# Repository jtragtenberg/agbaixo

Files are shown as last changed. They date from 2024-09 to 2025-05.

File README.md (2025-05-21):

# Agbaixo
Instrumento Agbaixo (também chamado de Agbau ou Agbaça), em processo de criação pelo BongarBit

Watch the video (https://youtu.be/48ikO1KuL8A)
Vídeo de Ninho Brown, do Bongarbit, tocando o Agbau no Centro Cultural Grupo Bongar - Guitinho da Xambá em Olinda/PE

Na pasta Arduino está o Firmware em C++ do microcontrolador AVR responsável por receber os dados dos botões e sensores e mandar por protocolo MIDI USB para o Bela

Na pasta Bela está a engine de som em duas variantes para reproduzir os samples em tempo real juntamente com um processamento do sinal com uma envoltória exponencial otimizado para reduzir a demanda de processamento do Bela, opções de configuração do modo de disparo dos samples

# Para mandar o código para o Arduino:

Baixe e instale o Arduino na versão legado (1.8.x) em https://www.arduino.cc/en/software

Abra o programa Arduino (Arduino IDE)

Instale as bibliotecas colocando no diretório onde o Arduino for instalado, dentro da pasta libraries, todas as pastas que estão em Arduino/libraries deste repositório.

Na IDE do Arduino, vá nas configurações (File > Preferences) e adicione o texto na caixa de texto "Additional Board Manager URLs" o seguinte link: https://raw.githubusercontent.com/sparkfun/Arduino_Boards/main/IDE_Board_Manager/package_sparkfun_index.json

Vá em Tools>Board>Boards Manager e faça uma busca por Sparkfun AVR Boards e clique no botão "Install"

Vá em Tools>Board> e selecione a placa Arduino Pro Micro

Vá em Tools>Processor: e selecione o "ATmega 32u4 (5v, 16MHz)"

Identifique quais opções existem em Tools>Port>

Conecte o arduino no USB do computador

Note qual foi a opção nova que apareceu no submenu Tools>Port> e selecione ela

Abra o arquivo Arduino/agbaixo/agbaixo.ino e clique na barra de ferramentas da IDE do Arduino no botão "Upload" (o segundo da esquerda pra direita)

Se tudo der certo o código será enviado para a memória do Arduino.

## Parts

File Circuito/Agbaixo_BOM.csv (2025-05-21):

Reference | Value | Datasheet | Footprint | Qty | DNP
D1,D2,D3,D4,D5,D6,D7,D8,D9,D10,D11,D12,D13,D14,D15,D16 | D | ~ | Diode_THT:D_T-1_P5.08mm_Horizontal | 16
J1,J2 | Conn_01x12_Socket | ~ | Connector_PinSocket_2.54mm:PinSocket_1x12_P2.54mm_Vertical | 2
J3,J5,J6,J7,J8,J9,J10,J11,J12,J13,J14,J15,J16,J17,J18,J19,J20,J21,J22,J23 | Conn_01x02_Socket | ~ | Connector_JST:JST_EH_B2B-EH-A_1x02_P2.50mm_Vertical | 20
J4 | Conn_01x03_Socket | ~ | Connector_JST:JST_EH_B3B-EH-A_1x03_P2.50mm_Vertical | 1
J24,J25,J26,J27,J28,J29,J30,J31,J32,J33,J34,J35,J36,J37,J38,J39 | Conn_01x02_Pin | ~ | Connector_PinSocket_2.54mm:PinSocket_1x02_P2.54mm_Vertical | 16
R1,R2,R3,R4 | 220R | ~ | Resistor_THT:R_Axial_DIN0204_L3.6mm_D1.6mm_P5.08mm_Horizontal | 4

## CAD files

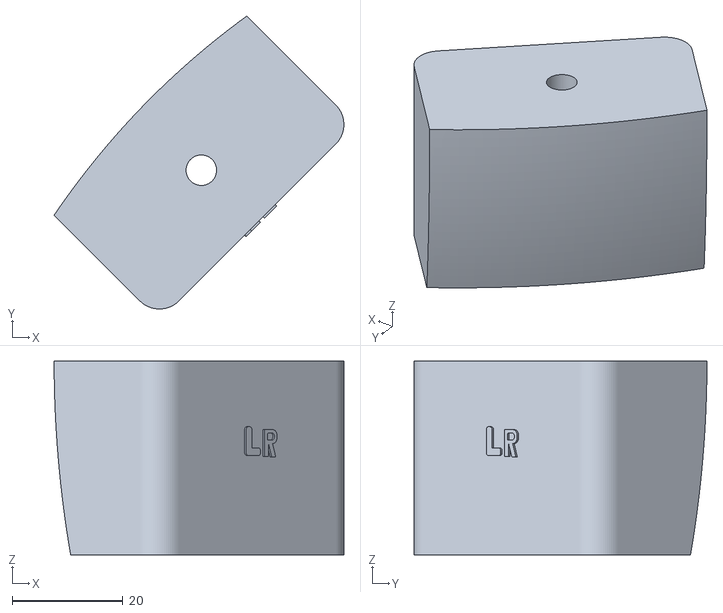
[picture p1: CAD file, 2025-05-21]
Structure/Cover_Holders/Piece1.stl
52.3 x 52.9 x 35.0

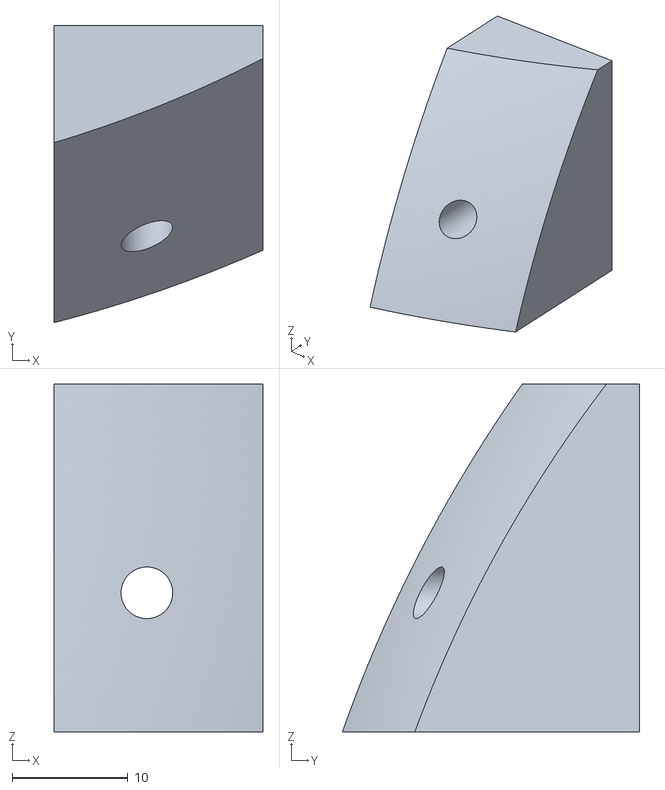
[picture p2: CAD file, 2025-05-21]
Structure/PCB_Base/pe2.stl
18.0 x 25.6 x 30.0

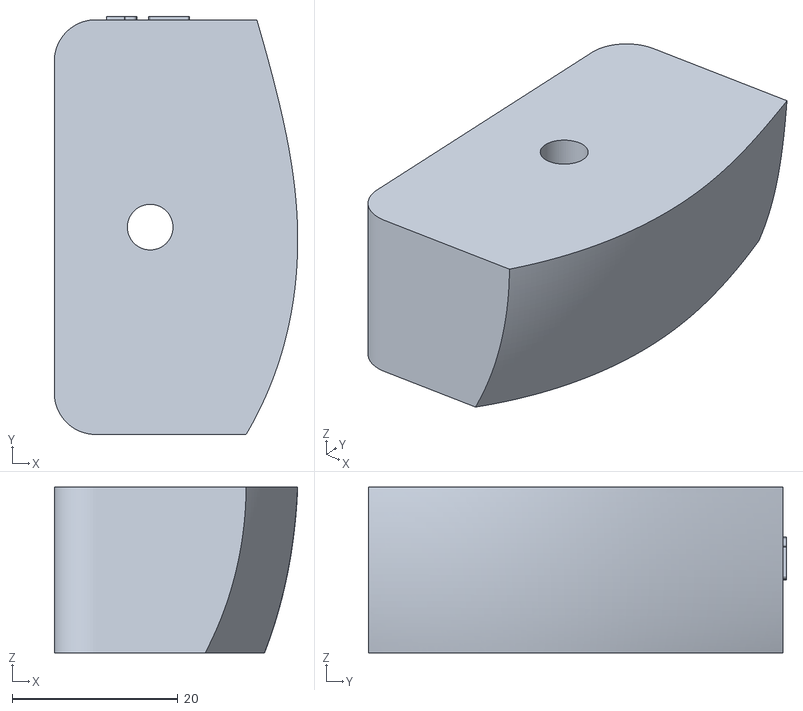
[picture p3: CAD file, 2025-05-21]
Structure/Cover_Holders/Piece6.stl
29.3 x 50.4 x 20.0

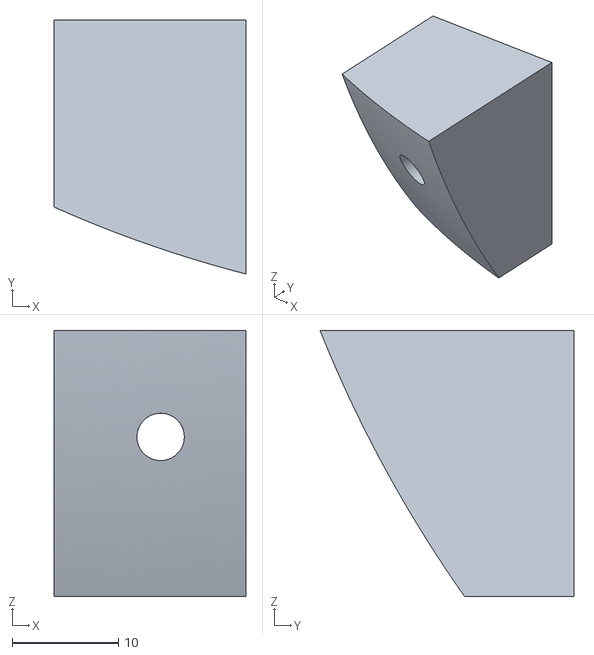
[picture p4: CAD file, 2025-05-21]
Structure/PCB_Base/pe4.stl
18.0 x 23.9 x 25.0

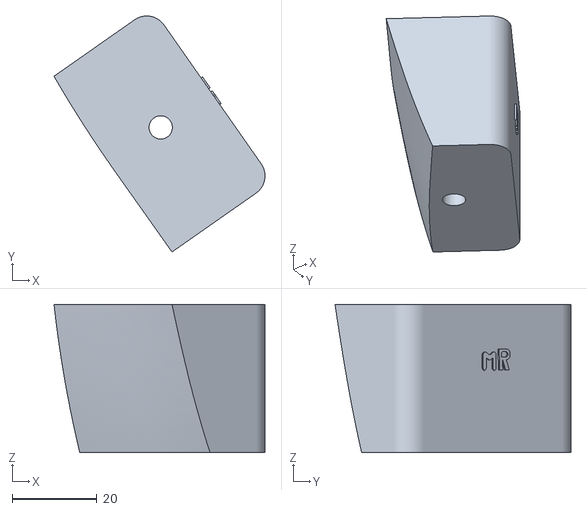
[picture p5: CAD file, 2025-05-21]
Structure/Cover_Holders/Piece3.stl
49.8 x 55.7 x 35.0

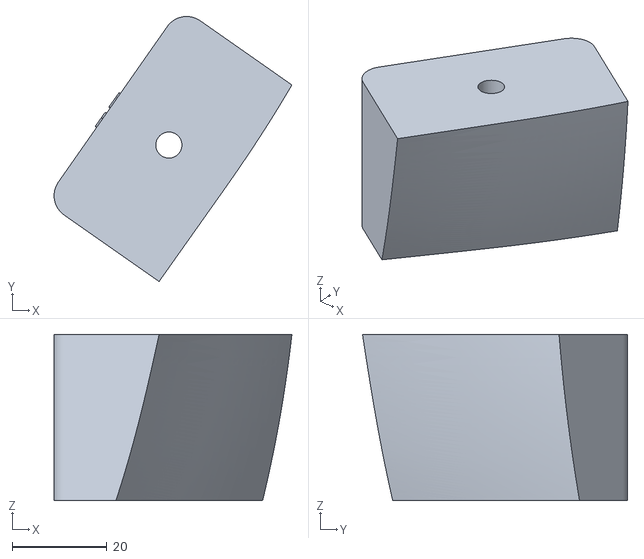
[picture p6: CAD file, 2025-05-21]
Structure/Cover_Holders/Piece4.stl
50.1 x 55.9 x 35.0

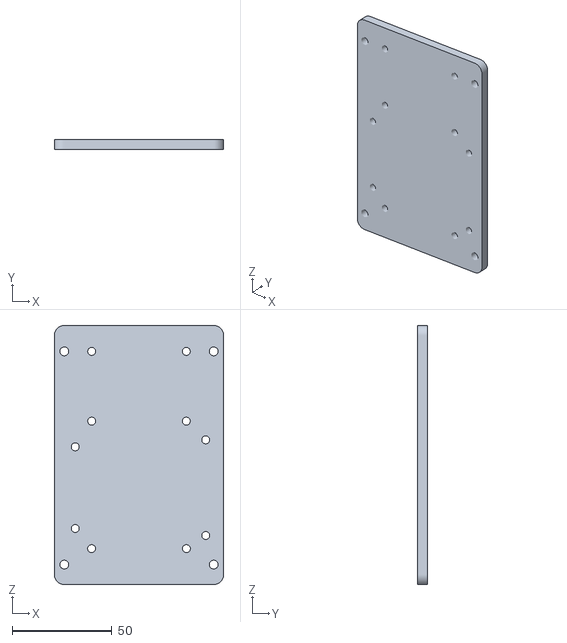
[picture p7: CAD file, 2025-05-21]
Structure/PCB_Base/base.stl
85.0 x 5.00 x 130.0

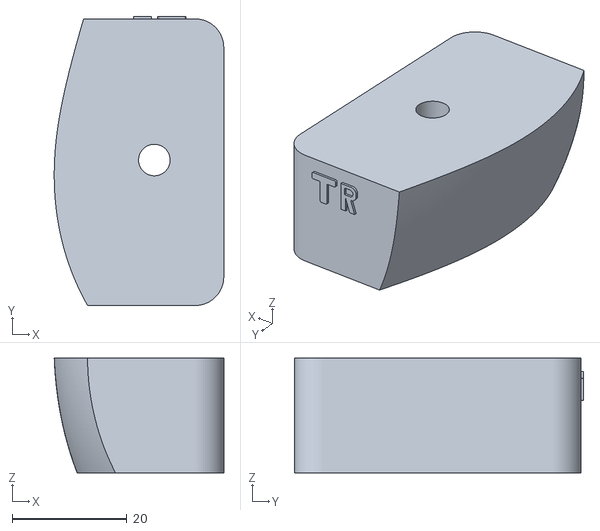
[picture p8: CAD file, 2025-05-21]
Structure/Cover_Holders/Piece5.stl
29.6 x 50.4 x 20.0

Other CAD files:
Structure/PCB_Base/pe1.stl
Structure/Cover_Holders/Piece2.stl
Structure/PCB_Base/pe3.stl
Structure/Cover_Holders/agbaixo_pieces.f3d
Structure/PCB_Base/Agbaixo_Base.f3d

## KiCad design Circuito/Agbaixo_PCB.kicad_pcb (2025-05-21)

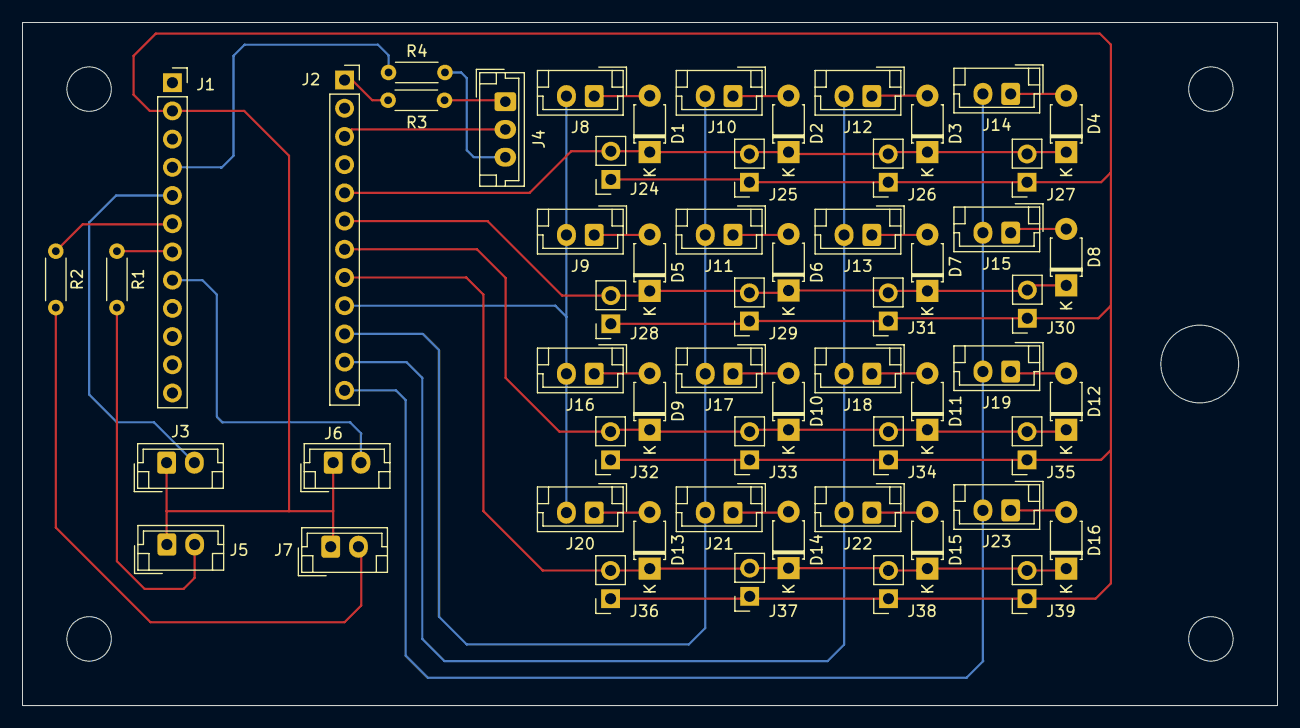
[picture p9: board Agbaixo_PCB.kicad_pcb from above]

Board: 2 copper layers, 113.0 x 61.5 mm, 59 parts (0 on the bottom side), 36 nets.

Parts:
D1, D2, D3, D4, D5, D6, D7, D8, D9, D10, D11, D12, D13, D14, D15, D16: D; D_T-1_P5.08mm_Horizontal
J1, J2: Conn_01x12_Socket; PinSocket_1x12_P2.54mm_Vertical
J3, J5, J6, J7, J8, J9, J10, J11, J12, J13, J14, J15, J16, J17, J18, J19, J20, J21, J22, J23: Conn_01x02_Socket; JST_EH_B2B-EH-A_1x02_P2.50mm_Vertical
J4: Conn_01x03_Socket; JST_EH_B3B-EH-A_1x03_P2.50mm_Vertical
J24, J25, J26, J27, J28, J29, J30, J31, J32, J33, J34, J35, J36, J37, J38, J39: Conn_01x02_Pin; PinSocket_1x02_P2.54mm_Vertical
R1, R2, R3, R4: 220R; R_Axial_DIN0204_L3.6mm_D1.6mm_P5.08mm_Horizontal

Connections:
unnamed: D1.2 (A), J8.1
unnamed: D1.1 (K), D2.1 (K), D3.1 (K), D4.1 (K), J2.5, J24.2, J25.2, J26.2, J27.2
unnamed: D2.2 (A), J10.1
unnamed: D3.2 (A), J12.1
unnamed: D4.2 (A), J14.1
unnamed: D5.2 (A), J9.1
unnamed: D5.1 (K), D6.1 (K), D7.1 (K), D8.1 (K), J2.6, J28.2, J29.2, J30.2, J31.2
unnamed: D6.2 (A), J11.1
unnamed: D7.2 (A), J13.1
unnamed: D8.2 (A), J15.1
unnamed: D9.2 (A), J16.1
unnamed: D10.2 (A), J17.1
unnamed: D9.1 (K), D10.1 (K), D11.1 (K), D12.1 (K), J2.7, J32.2, J33.2, J34.2, J35.2
unnamed: D11.2 (A), J18.1
unnamed: D12.2 (A), J19.1
unnamed: D13.2 (A), J20.1
unnamed: D13.1 (K), D14.1 (K), D15.1 (K), D16.1 (K), J2.8, J36.2, J37.2, J38.2, J39.2
unnamed: D14.2 (A), J21.1
unnamed: D15.2 (A), J22.1
unnamed: D16.2 (A), J23.1
unnamed: J1.2, J3.1, J5.1, J6.1, J7.1, J24.1, J25.1, J26.1, J27.1, J28.1, J29.1, J30.1, J31.1, J32.1, J33.1, J34.1, J35.1, J36.1, J37.1, J38.1, J39.1
unnamed: J1.4, R4.1
unnamed: J1.5, J3.2
unnamed: J1.6, R2.1
unnamed: J1.7, R1.1
unnamed: J1.8, J6.2
unnamed: J2.1, R3.1
unnamed: J2.3, J4.2
unnamed: J4.1, R3.2
unnamed: J4.3, R4.2
unnamed: J5.2, R1.2
unnamed: J7.2, R2.2
unnamed: J2.10, J10.2, J11.2, J17.2, J21.2
unnamed: J2.11, J12.2, J13.2, J18.2, J22.2
unnamed: J2.12, J14.2, J15.2, J19.2, J23.2
unnamed: J2.9, J8.2, J9.2, J16.2, J20.2

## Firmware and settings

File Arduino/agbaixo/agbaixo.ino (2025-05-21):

#include <Keypad.h>
#include <MIDIUSB.h>
#include <Bounce2.h>


//  GENERAL VARIABLES
const int MIDI_CHANNEL = 9;
const byte LINHAS = 4;
const byte COLUNAS = 4;
byte pinosColunas[LINHAS] = {2, 3, 4, 5};
byte pinosLinhas[COLUNAS] = {9, 8, 7, 6};
const byte pinoBotaoModo = 15;
const byte pinoLedBotaoModo = A1;
const byte pinoLooperLED = A2;
const byte pinoLooperPedal = A3;
char hexaKeys[LINHAS][COLUNAS] = {
  {'0', '4', '8', 'C'},
  {'1', '5', '9', 'D'},
  {'2', '6', 'A', 'E'},
  {'3', '7', 'B', 'F'}
};
Keypad teclado = Keypad(makeKeymap(hexaKeys), pinosLinhas, pinosColunas, LINHAS, COLUNAS); //initialize an instance of class NewKeypad
String msg;
int key_order[LINHAS * COLUNAS] = {
  1, 5, 9, 13,
  2, 6, 10,  14,
  3, 7, 11, 15,
  4, 8, 12, 16
};
const byte notaMidi[LINHAS * COLUNAS] = {
  60, 64, 68, 72,
  61, 65, 69, 73,
  62, 66, 70, 74,
  63, 67, 71, 75
};
const byte divisoesDoCompasso[8] = {
  2, 3, 4,
    6, 8,
  12, 16, 32
};
bool chavesApertadas [LINHAS * COLUNAS] = {
  false, false, false, false,
  false, false, false, false,
  false, false, false, false,
  false, false, false, false
};
int velocity = 100;

// TAP TEMPO VARIABLES
bool modoRepeat = false;
bool ttwaspressed = false;
int ultimoBotao[2];
int ultimoBaixo = 3;
int bpm = 120;
unsigned long previousMillis = 0;
unsigned long previousMillisMetro = 0;
int ledState = LOW;
Bounce botaoModo = Bounce();
int botoesApertados = 0;
unsigned long tempoBotao = 0;
unsigned long tempoBotaoAnterior = 0;

// LOOPER VARIABLES
Bounce looperPedal = Bounce();
bool isRecording = false;
bool isPlaying = false;
bool isOverdubbing = false;
bool ledStateLooper = false;
struct MidiMessage {
  byte type;
  //byte channel;
  byte data1;
  //byte data2;
  unsigned long timestamp;
};
const unsigned int loopbuffersize = 64;
const unsigned int maxOverdubLayers = 3;
MidiMessage midiLoop[maxOverdubLayers][loopbuffersize];
byte NloopMsgs[maxOverdubLayers];  // Number of messages in each layer
int currentLayer = 0;
unsigned long loopStartTime = 0;
unsigned long loopDuration = 0;
unsigned long currentLoopTime = 0;
int currentblinkt = 0;
int previousblinkt = 0;
int blinktime = 0;

// SETUP
void setup() {
  Serial.begin(9600);
  pinMode(pinoLedBotaoModo, OUTPUT);
  pinMode(pinoLooperLED, OUTPUT);
  botaoModo.attach(pinoBotaoModo, INPUT_PULLUP);
  botaoModo.interval(10);
  looperPedal.attach(pinoLooperPedal, INPUT_PULLUP);
  looperPedal.interval(10);
}

void loop(){
  //  BUTTON READING & DEBOUNCE
  if (teclado.getKeys()) {
    for (int i = 0; i < LIST_MAX; i++) {
      if (teclado.key[i].stateChanged) {
        switch (teclado.key[i].kstate) {  // Report active key state : IDLE, PRESSED, HOLD, or RELEASED
          case PRESSED:
              msg = " APERTADA.";
              if (key_order[teclado.key[i].kcode] > 8) { //se for botão
                dispararBotao(teclado.key[i].kcode);
              } else { //se for baixo
                dispararBaixo(teclado.key[i].kcode);
              }
              break;

          case HOLD:
            msg = " SEGURADA.";
            break;

          case RELEASED:
              msg = " SOLTA.";
              if (key_order[teclado.key[i].kcode] > 8) {
                soltarBotao(teclado.key[i].kcode);
              } else {
                soltarBaixo(teclado.key[i].kcode);
              }
              break;

          case IDLE:
            msg = " SOLTISSIMA.";
        }
        Serial.print("Tecla ");
        Serial.print(key_order[teclado.key[i].kcode]);
        Serial.println(msg);
      }
    }
  }

  //  TAP TEMPO
  botaoModo.update();
  if (botaoModo.fell()) {
    Serial.println("APERTOU MODO");
    tempoBotaoAnterior = tempoBotao;
    tempoBotao = millis();
    unsigned long intervalo = (tempoBotao - tempoBotaoAnterior);
    unsigned long bpmBotao = 1000. / intervalo * 60.;
    Serial.println(bpmBotao);
    bpm = bpmBotao;
    modoRepeat = true;
    Serial.println("MODO REPEAT");
    previousMillis = millis();
  }

  int botaoModoState = botaoModo.read();
  if (botaoModoState == LOW  && botaoModo.currentDuration() > 1000) {
    modoRepeat = false;
    Serial.println("MODO NOTA");
  }

  if (modoRepeat) {
    float interval = (1000 / bpm) * 60;
    unsigned long currentMillisMetro = millis();

    if (currentMillisMetro - previousMillisMetro > (interval / 2)) {
      previousMillisMetro = currentMillisMetro;

      // if the LED is off turn it on and vice-versa:
      if (ledState == LOW) {
        ledState = HIGH;
        digitalWrite(pinoLedBotaoModo, ledState);
      }
      else {
        ledState = LOW;
        digitalWrite(pinoLedBotaoModo, ledState);
        // set the LED with the ledState of the variable:
      }
    }

    unsigned long currentMillis = millis();

//TODO: não colocar o noteOff logo depois do noteON
//TODO: Corrigir algoritmo de contagem de botões apertados

    if (botoesApertados > 0) {
      if (currentMillis - previousMillis > (interval / divisoesDoCompasso[ultimoBaixo - 1] * 4.)) {
        previousMillis = currentMillis;
        noteOff(MIDI_CHANNEL - 1, ultimoBotao[1], 0);   // canal_midi, nota_midi, velocity_midi
        MidiUSB.flush();

        noteOn(MIDI_CHANNEL - 1, ultimoBotao[0], velocity);   // canal_midi, nota_midi, velocity_midi
        MidiUSB.flush();
        ttwaspressed = true;
      }
    }
    if (botoesApertados <= 0 && ttwaspressed){
        noteOff(MIDI_CHANNEL - 1, ultimoBotao[0], velocity);   // canal_midi, nota_midi, velocity_midi
        MidiUSB.flush();
        ttwaspressed = false;
    }
  } 
  else {
    digitalWrite(pinoLedBotaoModo, LOW);
  }

  //  LOOP
  loopstate();
  loopLED();
}

/////////////////////////////////////////////////////////////////////////////////////

//NOTE ON
void noteOn(byte channel, byte pitch, byte velocity) {
    midiEventPacket_t noteOn = {
    static_cast<uint8_t>(0x09),
    static_cast<uint8_t>(0x90 | channel),
    static_cast<uint8_t>(pitch),
    static_cast<uint8_t>(velocity)
};
  MidiUSB.sendMIDI(noteOn);
  if (isRecording) {
    recordMessage(0x09, pitch);
  }
}

//NOTE OFF
void noteOff(byte channel, byte pitch, byte velocity) {
  midiEventPacket_t noteOff = {
    static_cast<uint8_t>(0x08),
    static_cast<uint8_t>(0x80 | channel),
    static_cast<uint8_t>(pitch),
    static_cast<uint8_t>(velocity)
};
  MidiUSB.sendMIDI(noteOff);
  if (isRecording) {
    recordMessage(0x08, pitch);
  }
}

//CC
void controlChange(byte channel, byte control, byte value) {
    midiEventPacket_t event = {
    static_cast<uint8_t>(0x0B),
    static_cast<uint8_t>(0xB0 | channel),
    static_cast<uint8_t>(control),
    static_cast<uint8_t>(value)
};
  MidiUSB.sendMIDI(event);
}

void dispararBotao(int keyCode_) {
  if (modoRepeat) {
    //começa detecção de velocity com piezo
    botoesApertados++;
    Serial.println(botoesApertados);
    chavesApertadas[keyCode_] = true;
    ultimoBotao[1] = ultimoBotao[0];
    ultimoBotao[0] = notaMidi[keyCode_];
  } 
  else {
    noteOn(MIDI_CHANNEL - 1, notaMidi[keyCode_], velocity);   // Channel 0, middle C, normal velocity
    MidiUSB.flush();
  }
}

void soltarBotao(int keyCode_) {
  if (modoRepeat) {
    botoesApertados--;
    Serial.println(botoesApertados);
    chavesApertadas[keyCode_] = false;
  } else {
    noteOff(MIDI_CHANNEL - 1, notaMidi[keyCode_], 0);  // Channel 0, middle C, normal velocity
    MidiUSB.flush();
  }
}

void dispararBaixo(int keyCode_) {
  if (modoRepeat) {
    ultimoBaixo = key_order[keyCode_];
    chavesApertadas[keyCode_] = true;
  } else {
    //Dispara a nota
    noteOn(MIDI_CHANNEL - 1, notaMidi[keyCode_], velocity);   // Channel 0, middle C, normal velocity
    MidiUSB.flush();
  }
}

void soltarBaixo(int keyCode_) {
  if (modoRepeat) {
  chavesApertadas[keyCode_] = false;
  } else {
    noteOff(MIDI_CHANNEL - 1, notaMidi[keyCode_], 0);  // Channel 0, middle C, normal velocity
    MidiUSB.flush();
  }
}

int contagemDeBotoesApertados(){
  int c = 0;
  for (int i=9; i<=15; i++){
    if (chavesApertadas[i]) {
      c++;
    }
  }
  return c;
}



void loopstate(){
  looperPedal.update();
  if (looperPedal.fell()) {
    if (!isRecording && !isPlaying) {
      startRecording();
    } 
    else if (isRecording && !isPlaying) {
      stopRecording();
    } 
    else if (isPlaying && !isOverdubbing) {
      startOverdub();
    }
    else if (isPlaying && isOverdubbing){
      stopOverdub();
    }
  }
  if (isRecording && NloopMsgs[currentLayer]==loopbuffersize){
    stopRecording();
  }
  if (isOverdubbing && ((currentLoopTime%loopDuration)<=0.01 || NloopMsgs[currentLayer]==loopbuffersize)){
    stopOverdub();
  }
  if (isPlaying) {
    int looperpedalstate = looperPedal.read();
    if (looperpedalstate == LOW && looperPedal.currentDuration() > 1000) {
      isRecording = false;
      isPlaying = false;
      isOverdubbing = false;
      ledStateLooper = false;
      for (int i=0;i<loopbuffersize;i++){
        for (int layer=0; layer<maxOverdubLayers; layer++) {
          midiLoop[layer][i].type = 0;
          //midiLoop[layer][i].channel = 0;
          midiLoop[layer][i].data1 = 0;
          //midiLoop[layer][i].data2 = 0;
          midiLoop[layer][i].timestamp = 0;
        }
      }
      for (int layer=0; layer<maxOverdubLayers; layer++) {
        NloopMsgs[layer] = 0;
      }
      currentLoopTime = 0;
      loopStartTime = 0;
      currentLayer = 0;
      currentblinkt = 0;
      previousblinkt = 0;
      blinktime = 0;
      Serial.println("ERASED LOOP");
    }
    else{
      playLoop();
    }
  }
}



void startRecording() {
  Serial.println("Recording Started");
  isRecording = true;
  isPlaying = false;
  NloopMsgs[currentLayer] = 0;  // Reset the current layer's message count
  if (currentLayer==0){
    loopStartTime = millis();
  }
}

void stopRecording() {
  Serial.println("Recording Stopped");
  isRecording = false;
  isPlaying = true;

  NloopMsgs[currentLayer];  // Set loopLength to the current layer's message count

  if (currentLayer==0){
    loopDuration = millis() - loopStartTime;
  }
  previousblinkt = millis();
}



void startOverdub(){
  if (currentLayer < maxOverdubLayers) {
    Serial.println("Overdub Started");
    isOverdubbing = true;
    isRecording = true;
    currentLayer++;
    NloopMsgs[currentLayer] = 0;  // Start a new layer
  }
}

void stopOverdub(){
  Serial.println("Overdub Stopped");
  isOverdubbing = false;
  isRecording = false;
}



void recordMessage(byte type, byte data1) {
  if (NloopMsgs[currentLayer] < loopbuffersize) {
    midiLoop[currentLayer][NloopMsgs[currentLayer]].type = type;
   // midiLoop[currentLayer][NloopMsgs[currentLayer]].channel = channel;
    midiLoop[currentLayer][NloopMsgs[currentLayer]].data1 = data1;
   // midiLoop[currentLayer][NloopMsgs[currentLayer]].data2 = data2;
    midiLoop[currentLayer][NloopMsgs[currentLayer]].timestamp = millis() - loopStartTime;
    NloopMsgs[currentLayer]++;
  }
}

void playLoop() {
  currentLoopTime = millis() - loopStartTime;
  for (int layer = 0; layer <= currentLayer; layer++) {
    for (int i = 0; i < NloopMsgs[layer]; i++) {
      if (midiLoop[layer][i].timestamp <= currentLoopTime) {
        if (midiLoop[layer][i].type == 0x09) {
          noteOn(MIDI_CHANNEL, midiLoop[layer][i].data1, velocity);
          MidiUSB.flush();
        } else if (midiLoop[layer][i].type == 0x08) {
          noteOff(MIDI_CHANNEL, midiLoop[layer][i].data1, 0);
          MidiUSB.flush();
        }
        midiLoop[layer][i].timestamp += loopDuration;
      }
    }
  }
}



void loopLED(){
  if (!isRecording && !isPlaying) {
    digitalWrite(pinoLooperLED,LOW);
    ledStateLooper=false;
  } 
  else if (isRecording) {
    digitalWrite(pinoLooperLED,HIGH);
    ledStateLooper=true;
  } 
  else if (isPlaying) {
    blinkloop();
  }
}

void blinkloop(){
  int blinktime = loopDuration / 4;
  currentblinkt = millis();
  if (currentblinkt - previousblinkt >= blinktime) {
    previousblinkt = currentblinkt;
    if (!ledStateLooper) {
      digitalWrite(pinoLooperLED, HIGH);
      ledStateLooper = true;   
    } else {
      digitalWrite(pinoLooperLED, LOW);
      ledStateLooper = false;
    }
  }
}

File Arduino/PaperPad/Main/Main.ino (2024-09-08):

#include <MIDIUSB.h>
#include <MIDI.h>

// SETUP
const int PadPin = 21;

//MIDI settings
MIDI_CREATE_DEFAULT_INSTANCE();
int note = 38;
int channel = 1;

unsigned long ISRtime = 500;  // interruption time in microseconds (e.g., 500000 us = 0.5 seconds)
void setup() {
  // Set the pads and buttons
  pinMode(PadPin,INPUT);
  // Initialize USB Serial for debugging (optional)
  Serial.begin(31250);
  MIDI.begin(channel);
  // Disable global interrupts while setting up the timer
  cli();
  // Convert microseconds to seconds
  double ISRtime_sec = ISRtime / 1000000.0;
  // Calculate the timer compare match register value based on blink time
  // F_CPU      = 16 MHz (16,000,000 Hz)
  // Prescaler  = 1024
  // Formula: OCR1A = (F_CPU / Prescaler) * (Blink Time in seconds) - 1
  unsigned long compareMatchValue = (16e6 / 1024) * ISRtime_sec - 1;
  // Configure Timer1
  TCCR1A = 0;
  TCCR1B = 0;
  TCCR1B |= (1 << WGM12);              // CTC mode
  TCCR1B |= (1 << CS10) | (1 << CS12); // Prescaler 1024
  OCR1A = compareMatchValue;           // Set compare match register value
  // Enable Timer Compare Interrupt
  TIMSK1 |= (1 << OCIE1A);
  // Enable global interrupts
  sei();
}



// INTERRUPTION ROUTINE

int padRead = 0;
float pressure = 0;
int s = 0;
ISR(TIMER1_COMPA_vect) {
  padRead = analogRead(PadPin);  // reads the input pin [0 : 1023]
  pressure = filter(padRead,pressure,0.6,0.9);
  key(pressure, 15, 5);
  //s = switchMode(map(pressure,0,750,0,127), note);
}



// LOOP ROUTINE (IN CASE OF TESTING)
void loop() {
}

//////////////////////////////////////////////////////////////////////////////////////////////////////////////////////////////////////////

//SWITCH MODE
const int switcht = 20; //ms
const int switchon = 25; // pressure threshold to activate the switch
const int switchoff = 15; // pressure threshold to deactivate the switch
int switchbuffer[2];
int switchoutput = 0; //switch velocity [0 -> 127]

int switchMode(int input, int note) {
  unsigned long t0 = 0; //ms
  switchbuffer[1] = switchbuffer[0];
  switchbuffer[0] = input;
  if (switchbuffer[0] >= switchon){
    if (switchoutput == 0) {
      noteOn(channel, 38, 127);
      MidiUSB.flush();
      t0 = millis(); // Start debounce timer
    }
    if (switchbuffer[0] != switchbuffer[1]){
      controlChange(0, 11, map(switchbuffer[0],switchon,127,0,127)); //Control Change 11 -> Expression Controller (mapped to pressure aftertouch)
      MidiUSB.flush();
    }
    switchoutput = 127;
  } 
  else if (switchbuffer[0] <= switchoff && (millis() - t0) >= switcht) {     // Debounce period has passed
    if (switchoutput == 127) {
      controlChange(channel,11,0);
      noteOff(channel, 38, 0);
      MidiUSB.flush();

    }
    switchoutput = 0;
  }
  return switchoutput;
}



// KEY MODE
int index = 0;
int debounce = 0;
const int winsize = 5;
float detection_buffer[winsize];
bool noteon = false;

void key(float pressure, float derthresh, float pthresh) {
  // auxiliar parameters which can be fine tuned
  const int derscale = 3;
  const int debouncesmps = 150;
  float der = 0;

  // allow readings of pressure according to the derivative scale chosen
  index++;
  if(index==derscale){

    //calculate the derivative of the pressure each derscale samples
    der = filter(Derivative(pressure),der,0.1,0.3);

    Serial.print("ref1, ");
    Serial.print(100);
    Serial.print("ref2, ");
    Serial.print(-30);
    Serial.print(", pressure, ");
    Serial.print(map(pressure,0,700,0,100));
    Serial.print(", derivative, ");
    Serial.println(der);

    // Update the deteection buffer
    for (int j = winsize - 1; j > 0; j--) {
      detection_buffer[j] = detection_buffer[j - 1];
    }
    detection_buffer[0] = der;
    //read over the velocity buffer to check if the peak is in the middle and all the samples are greater than the threshold 
    static int middle_index = winsize / 2;
    int threshaux = 0;
    float maxv = 0;
    bool threshcheck = false;
    bool peakcheck = false;
    for (int l = 0; l < winsize; l++){
      // check where is the peak of the buffer
      if (detection_buffer[l] > maxv){
        maxv = detection_buffer[l];
        } 
    }

    //if the peak is in the middle of the buffer and if it is greater than the threshold
    //Check conditions to trigger velocity and send MIDI message
    if (maxv == detection_buffer[middle_index] && maxv >= derthresh && debounce >= debouncesmps && !noteon) {
      //int v = value_buffer[0]-value_buffer[vwinsize-1];
      //noteOn(channel,note[0],map(v,0,400,0,127));
      noteOn(channel,note,maxv);
      MidiUSB.flush();
      debounce = 0;
      noteon = true;
    } 
    // If the pressure decays, turn the note off
    else if (pressure <= pthresh && noteon) {
      noteOff(channel,note,0);
      MidiUSB.flush();
      noteon = false;
    }
    index = 0;
  }
  debounce++;
}



//DERIVATIVE
float derivativeBuffer[5];  
float Derivative(int input) {
  for (int k = 1; k < 5; k++) {
    derivativeBuffer[k] = derivativeBuffer[k - 1];
  }
  derivativeBuffer[0] = input;
  return (float) 2.08 * derivativeBuffer[0] - 4 * derivativeBuffer[1] + 3 * derivativeBuffer[2] - 1.33 * derivativeBuffer[3] + 0.25 * derivativeBuffer[4];
  //Backwards Finite difference (http://en.wikipedia.org/wiki/Finite_difference_coefficients)
}



// EXPONENTIAL AVERAGING AND FORMATTING ADSR
float EWMA(float input, float filteredin, float alpha) {
  return ((1-alpha)*input) + (alpha * filteredin);
  //https://www.itl.nist.gov/div898/handbook/pmc/section4/pmc431.htm
}
float filter_buffer[2];
float filter(float input, float output, float alpha1, float alpha2){ // filters the input signal (exponencial average) dpeending if it is rising or decaying
  filter_buffer[1] = filter_buffer[0];
  filter_buffer[0] = input;
  if (filter_buffer[1] < filter_buffer[0]){ 
    output = (float) EWMA(filter_buffer[0],output,alpha1);
    } 
  else {
    output = (float) EWMA(filter_buffer[0],output,alpha2);
    }
  return output;
}



//MIDI MESSAGES

//CC
void controlChange(byte channel, byte control, byte value) {
    midiEventPacket_t event = {
    static_cast<uint8_t>(0x0B),
    static_cast<uint8_t>(0xB0 | channel),
    static_cast<uint8_t>(control),
    static_cast<uint8_t>(value)
};
  MidiUSB.sendMIDI(event);
}
//  in the case of sending midi using the serial port remeber to Initialize serial communication at MIDI stadard baud rate: 31250 -> Serial.begin(31250);
void sendControlChange(byte channel, byte control, byte value) {
  MIDI.sendControlChange(control, value, channel);
}

//NOTE ON
void noteOn(byte channel, byte pitch, byte velocity) {
    midiEventPacket_t noteOn = {
    static_cast<uint8_t>(0x09),
    static_cast<uint8_t>(0x90 | channel),
    static_cast<uint8_t>(pitch),
    static_cast<uint8_t>(velocity)
};
  MidiUSB.sendMIDI(noteOn);
}
void serialNoteOn(byte channel, byte pitch, byte velocity){
  MIDI.sendNoteOn(pitch, velocity, channel);
}
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

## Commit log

2024-01-03 Velocity nos Botoes
2024-01-26 adaptei o codigo arduino pra botoes novos
2025-05-21 Added sampler from other repo to this
2026-03-24 Remove Bela sampler project directories
